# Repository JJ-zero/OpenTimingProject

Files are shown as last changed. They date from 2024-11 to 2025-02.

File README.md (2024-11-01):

# Open Timing Project

This project targets to provide an easy to use system for timing of parkour speedruns and any similar events.

## How it works.
- You need one server and one gate node.
- The server node creates a `OpenTimingProject` WiFi with a captive portal hosting simple website showing data a current and previsous run.
- After gate node is connected you can start a new run by pressing the server node.
- The gate node connects to the WiFi and at press stops active run.

## Node colors
- **Green** - Open, ready to start a new run.
- **Red** - Run in progress.
- **Orange center ring** - Gate node not connected to the server wifi.
- **Blue loading animation** - Gate node starting up.
- **Purple loading animation** - Server node starting up.

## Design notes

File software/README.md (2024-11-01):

# Software
> Disclaimer: This whole project and the code especially is a work in progress and was created in a short time. I'm not fluent in cpp and most of this goes against the best practices. I'm aware and happy to aprove your PRs.

## Web app
OTP uses simple website that is served automatically after connecting to WiFi as a captive portal. You can found the non-minimalized version [here](./OpenTimingProject.html). The site has two main routines:
- Server checking that gets data from the server node and updates the site.
- Timer update that keeps time running for the user. 

The reason for *faking* the times is an attempt at optimalization and keeping server node free to recieve the more important requests from gates. When connected the site can detect new run and add show the history of previous runs. 

## API reference

### `/app/records`
Returns a JSON containing ID of current run, time since start of the run and time of the previous run. Times are in miliseconds.
#### Example:
This example is for run 12, that started 4.455 seconds ago and the previous run was 7.5 seconds long.
```json
{
    "current": 4455,
    "id": 12,
    "previous": 7500
}
```

### `/api/gate`
Ends the current run and returns simple text. Intended to be called by gates. Idealy should be a POST request in the future and accept the gate ID.

### `/api/state`
Returns the current state of the run.
- If run is in progress, returns status 202 and text `Running`.
- If run is not in progress, returns status 200 and text `None`.
This endpoint should be super light and fast to be called by gates. Gates use the status code to determine the state of the run.

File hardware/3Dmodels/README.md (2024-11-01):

## Notex to the 3D models
- All models are designed to print on my Prusa Mini+. You may need to adjust some offsets or sizes.
- The fits for components are not "pressfit" precise. You may need to adjust the sizes or use glue. Just a bit of hotglue worked for me.
- The `Top` is designed for trasparent filament to allow the LEDs to shine through. You may try to play with your slices settings to get desired effect. More infill will better refract the light but make it less bright.
- Near the spot for a charging module are two holes. You can insert a bit of trasparent filament as a light guide to make a "charging" indicator. Heat the filament to get in in place. 
- ESP8266 and the battery does not have a dedicated spot. I used just hotflued it in. Beaware that the 18650 fits super tight and you can not have any wires under or over it.

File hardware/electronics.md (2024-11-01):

# Electronics

## Required components
- ESP8266 - I used a Wemos D1 mini
- Battery charging module - I used [TP4056](https://www.laskakit.cz/nabijecka-li-ion-clanku-tp4056-s-ochranou-microusb/)
- Battery - I used [18650 with pre-soldered leads](https://www.gme.cz/v/1506728/westinghouse-18650-1s1p-li-ion-2600mah-akumulator)
- Neopixels light strip - 6 times 3 LEDs of the 60/m type (I think.)
- MX keayboard switches - 3 of any time you found pleasing, stronger switches are better (the lid is heavy)
- Switch - Just a simple on/off switch - [This](https://www.laskakit.cz/prepinac-kolebkovy-3a-250vac/) works in the 3D model
- Resistor - Pulldown for the switches. TBH I have no idea what value I used.

## Wiring
Main components:
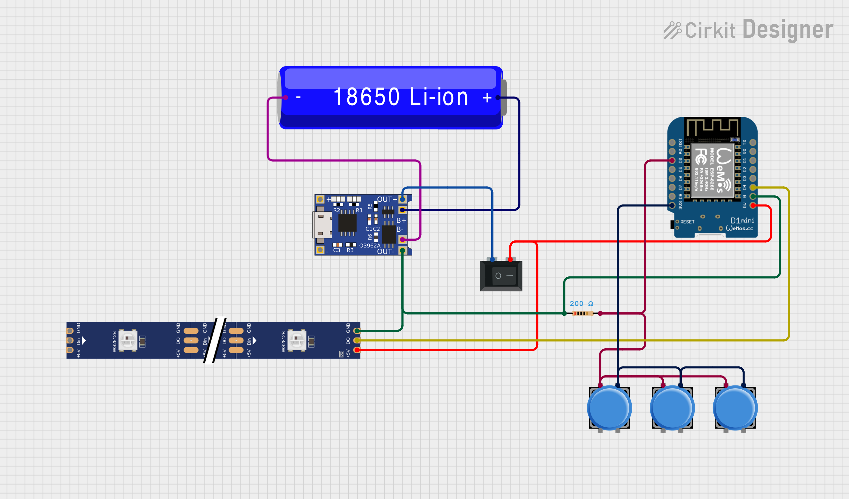
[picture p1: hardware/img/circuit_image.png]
Wiring diagram

LED strip signal directions:
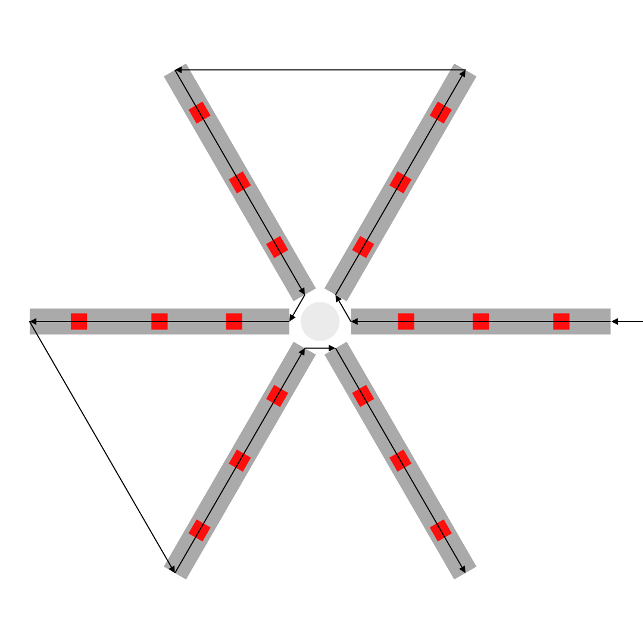
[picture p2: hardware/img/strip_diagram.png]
LED strip diagram


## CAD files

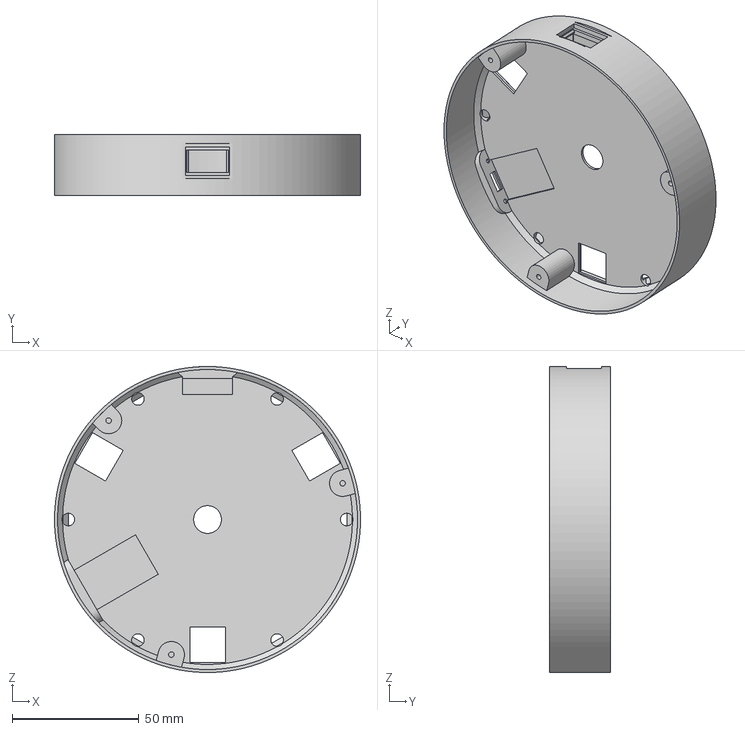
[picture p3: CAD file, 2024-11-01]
hardware/3Dmodels/MainBody.3mf
120.9 x 24.0 x 120.9 mm

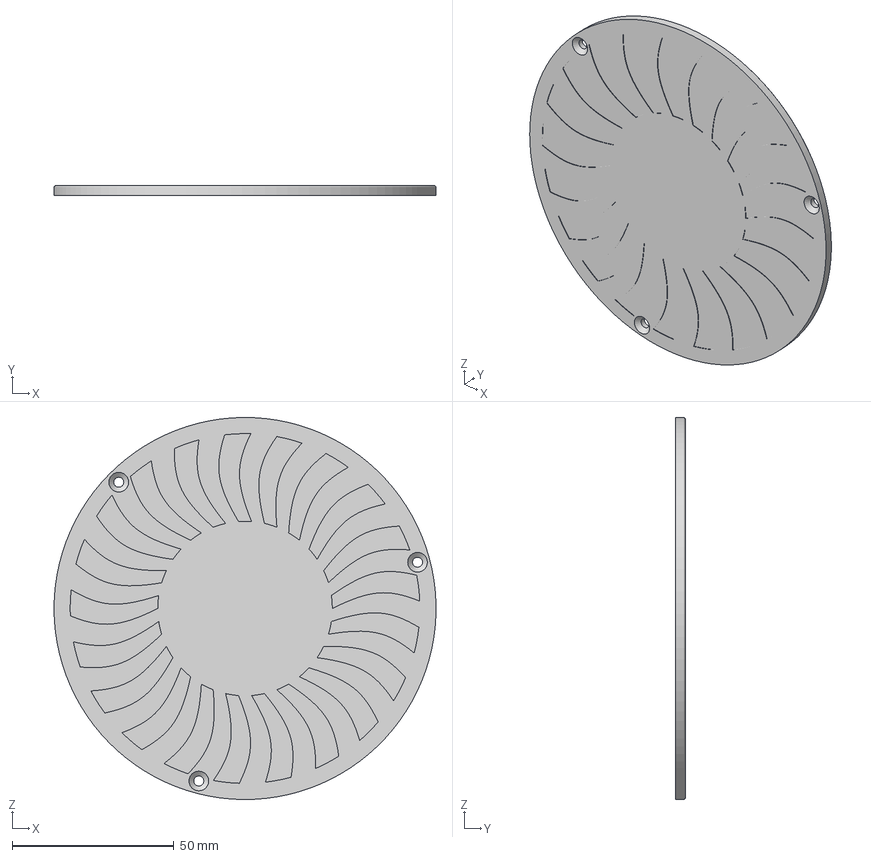
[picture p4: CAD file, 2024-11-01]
hardware/3Dmodels/BottomCover.3mf
118.2 x 3.20 x 118.2 mm

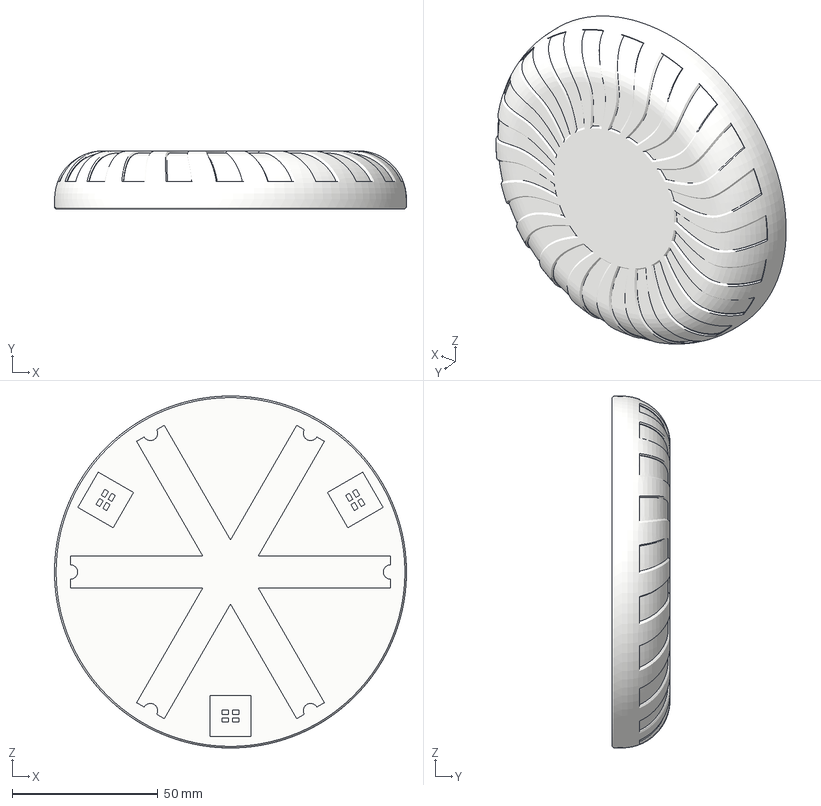
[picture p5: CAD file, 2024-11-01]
hardware/3Dmodels/Top.3mf
120.9 x 20.0 x 120.9 mm

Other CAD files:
hardware/3Dmodels/OpenTimingProject v5.f3d

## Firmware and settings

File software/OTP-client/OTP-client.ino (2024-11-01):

#include <Arduino.h>
#include <ESP8266WiFi.h>
#include <ESP8266WiFiMulti.h>
#include <ESP8266HTTPClient.h>
#include <WiFiClient.h>
#include <Adafruit_NeoPixel.h>


ESP8266WiFiMulti WiFiMulti;
const int buttonPin = 16;
bool buttonLastState = true;
int nextCheck = 0;
bool running = false;
bool showingDisconnected = false;

Adafruit_NeoPixel pixels(18, D4, NEO_GRB + NEO_KHZ800);

const uint32_t colorDisconnected = pixels.Color(130, 112, 5);
const uint32_t colorBlack = pixels.Color(0, 0, 0);
const uint32_t colorStop = pixels.Color(10, 200, 15);


void startupAnimation() {
  pixels.fill(colorBlack);
  pixels.show();

  for (int i = 0; i < 12; i++) {
    delay(80);
    pixels.fill(colorBlack);
    int index = 3*(i%6);
    pixels.setPixelColor(index, pixels.Color(0,0,255));
    pixels.setPixelColor(index+1, pixels.Color(0,0,255));
    pixels.setPixelColor(index+2, pixels.Color(0,0,255));
    pixels.show();
  }

  delay(100);
  pixels.fill(colorBlack);
  pixels.show();
}

void setDisconnected() {
  if (showingDisconnected) { return; };
  pixels.fill(colorBlack);
  for (int i = 0; i < 6; i++) {
    pixels.setPixelColor((i*3) + (2 * (1 - (i % 2))), colorDisconnected);
  }
  pixels.show();
  showingDisconnected = true;
}


void setup() {
  pinMode(buttonPin, INPUT);
  
  pixels.begin();
  pixels.setBrightness(95);
  startupAnimation();

  setDisconnected();

  WiFi.mode(WIFI_STA);
  WiFiMulti.addAP("OpenTimingProject");
  Serial.begin(115200);  
}

void loop() {
  if ((WiFiMulti.run() == WL_CONNECTED)) {
    if (showingDisconnected) { showingDisconnected = false; }
    bool buttonValue = digitalRead(buttonPin);
    if (buttonValue != buttonLastState) {
      buttonLastState = buttonValue;
      Serial.println("New button value");
      Serial.println(buttonValue);
      if (buttonValue) {
        WiFiClient client;
        HTTPClient http;

        http.setTimeout(500);
        if (http.begin(client, "http://192.168.255.1/api/gate")) {  // HTTP
          int httpCode = http.GET();

          // httpCode will be negative on error
          if (httpCode > 0) {
            // file found at server
            // if (httpCode == HTTP_CODE_OK || httpCode == HTTP_CODE_MOVED_PERMANENTLY) {}
          }

          http.end();
        }
        
        pixels.fill(colorStop);
        pixels.show();
      }
    }
    if (nextCheck < millis()) {
      WiFiClient client;
      HTTPClient http;

      if (http.begin(client, "http://192.168.255.1/api/state")) {  // HTTP
        int httpCode = http.GET();
        // httpCode will be negative on error
        // if (httpCode > 0) {
          // file found at server
          // if (httpCode == HTTP_CODE_OK || httpCode == HTTP_CODE_MOVED_PERMANENTLY) {}
        // }
        if (httpCode == HTTP_CODE_ACCEPTED) {
          pixels.fill(pixels.Color(255,15,10));
          pixels.show();
        } else if (httpCode == HTTP_CODE_OK) {
          pixels.fill(colorStop);
          pixels.show();
        }
        http.end();
        nextCheck = millis() + 500;
      }
    }
  } else if (WiFiMulti.run() == WL_DISCONNECTED) {
    setDisconnected();
    delay(200);
  } else {
    setDisconnected();
    delay(200);
  }
}

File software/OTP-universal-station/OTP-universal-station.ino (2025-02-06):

#include <Arduino.h>
#include <ESP8266WiFi.h>
#include <DNSServer.h>
#include "settings.h"

#define BATTERY_PIN A0
#define BATTERY_EMPTY 210
#define BATTERY_FULL 266

int mode = 0;
// Mode 0 - Base mode - Hosting AP and timming server
// Mode 1 - Satelite mode - Connecting to open WiFi and working as a satelite
// Mode 2 - Private satelite mode - Connecting to private WiFi. May be in "high performance mode"
const int buttonPin = 16;

// Base logic variables
bool buttonLastState = false;

/*
To be used:
tone(D5, 6400, 80);
*/


int wifi_scan() {
  WiFi.mode(WIFI_STA);
  WiFi.disconnect();
  delay(100);

  Serial.println(F("Starting WiFi scan..."));

  int scanResult = WiFi.scanNetworks(
    false, // asynvc
    true // hidden
  );
  if (scanResult == 0) {
    return 0;
  }

  String ssid;
  int32_t rssi;
  uint8_t encryptionType;
  uint8_t *bssid;
  int32_t channel;
  bool hidden;

  for (int8_t i = 0; i < scanResult; i++) {
    WiFi.getNetworkInfo(i, ssid, encryptionType, rssi, bssid, channel, hidden);
    if (ssid == open_ssid) {
      return 1;
    }
    if (ssid == private_ssid) {
      return 2;
    }
  }
  return 0;
}


void setup() {
  Serial.begin(115200);

  Serial.println("\nInitialization of pixels...");
  init_pixels();
  pixelsBootAnimation();
  
  // Check WiFi
  // - Setup for debug
  Serial.println(F("\nScannig for known hotspots..."));
  
  mode = wifi_scan();
  Serial.print("WiFi scan:");  
  Serial.println(mode);
    
  pinMode(buttonPin, INPUT);

  switch (mode) {
    case 0: setupBase(); break;
    case 1: setupSatelite(); break;
    case 2: break;
  }
  Serial.println("\nSetup completed...");
}

void loop() {
  switch (mode) {
    case 0: loopBase(); break;
    case 1: loopSatelite(); break;
    case 2: break;
  }
  pixelsAnimate();
}

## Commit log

2024-11-01 Init commit
    [BottomCover.3mf, MainBody.3mf, OpenTimingProject v5.f3d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]
2024-12-18 Quick satelite copy-paste and testing buzzer
    [OTP-universal-station.ino, satelite.ino]
2025-02-06 Adding (usualy) working OTA and battery endpoint
